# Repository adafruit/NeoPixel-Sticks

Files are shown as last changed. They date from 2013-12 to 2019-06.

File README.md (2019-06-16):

# NeoPixel Stick

__Format is EagleCAD schematic and board layout__

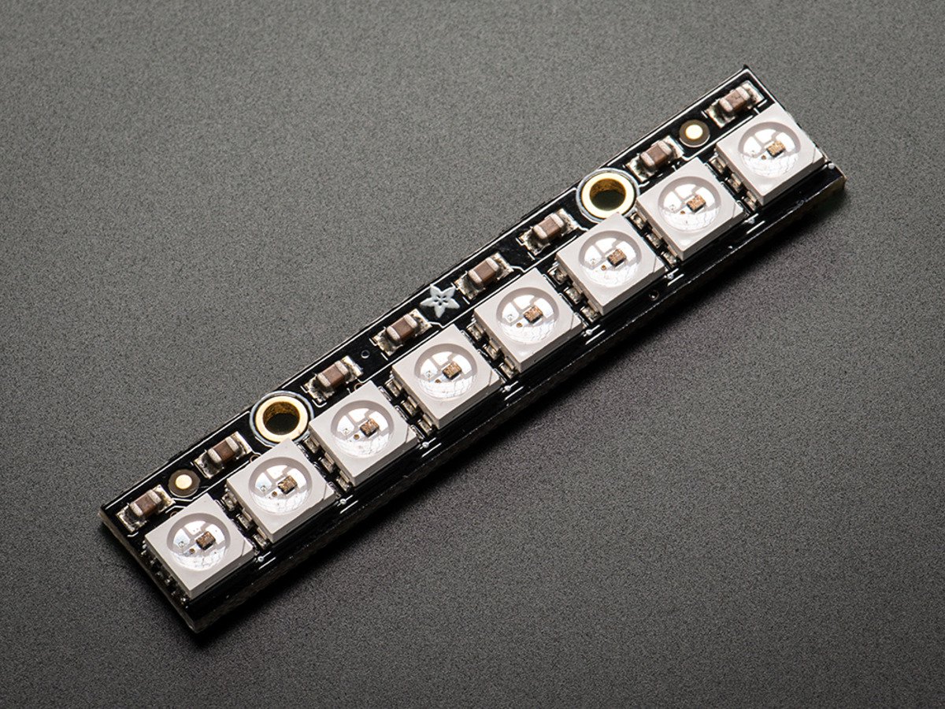
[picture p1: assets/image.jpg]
<a href="http://www.adafruit.com/products/1426"><br/>Click here to purchase one from the Adafruit shop</a>

Make your own little LED strip arrangement with this stick of NeoPixel LEDs. We crammed 8 of the tiny 5050 (5mm x 5mm) smart RGB LEDs onto a PCB with mounting holes and a chainable design. Use only one microcontroller pin to control as many as you can chain together! Each LED is addressable as the driver chip is inside the LED. Each one has ~18mA constant current drive so the color will be very consistent even if the voltage varies, and no external choke resistors are required making the design slim. Power the whole thing with 5VDC (4-7V works) and you're ready to rock.

The LEDs are 'chainable' by connecting the output of one stick into the input of another - see the photo above. There is a single data line with a very timing-specific protocol. Since the protocol is very sensitive to timing, it requires a real-time microconroller such as an AVR, Arduino, PIC, mbed, etc. It cannot be used with a Linux-based microcomputer or interpreted microcontroller such as the netduino or Basic Stamp. Our wonderfully-written [Neopixel library for Arduino supports these pixels!](https://github.com/adafruit/Adafruit_NeoPixel) As it requires hand-tuned assembly it is only for AVR cores but others may have ported this chip driver code so please google around. An 8MHz or faster processor is required.

Comes as a single stick with 8 individually addressable RGB LEDs assembled and tested.

[Our detailed NeoPixel Uberguide has everything you need to use NeoPixels in any shape and size. Including ready-to-go library & example code for the Arduino UNO/Duemilanove/Diecimila, Flora/Micro/Leonardo, Trinket/Gemma, Arduino Due & Arduino Mega/ADK (all versions)](http://learn.adafruit.com/adafruit-neopixel-uberguide)

## License

Adafruit invests time and resources providing this open source design, 
please support Adafruit and open-source hardware by purchasing 
products from Adafruit!

Designed by Adafruit Industries.  
Creative Commons Attribution, Share-Alike license, check license.txt for more information
All text above must be included in any redistribution

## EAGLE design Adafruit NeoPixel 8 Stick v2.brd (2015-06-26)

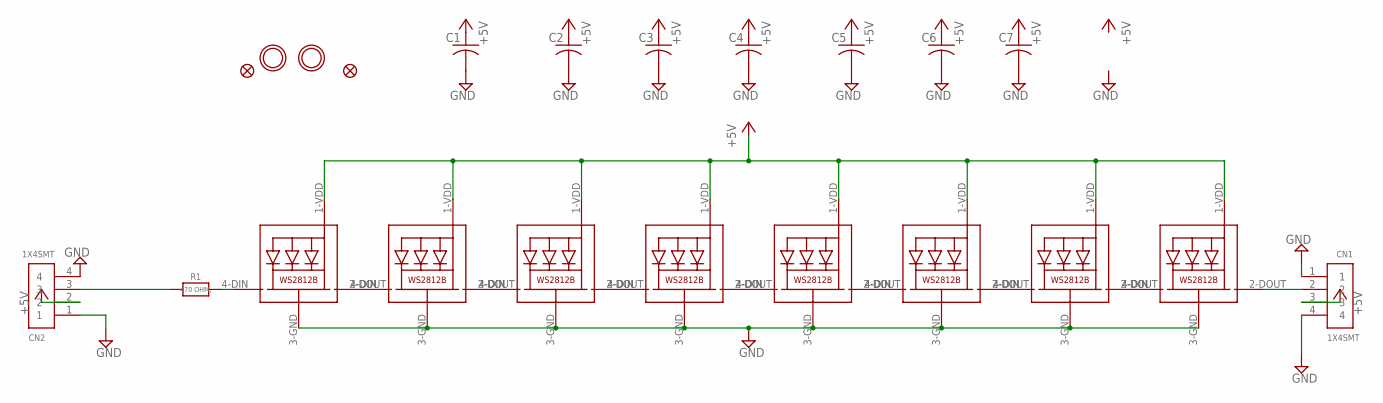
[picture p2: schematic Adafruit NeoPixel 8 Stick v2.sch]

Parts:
C1, C2, C3, C4, C5, C6, C7: C-USC0805K; C0805K
CN1, CN2: 1X4SMT; 1X4-SMT
FID1, FID3: FIDUCIAL""; FIDUCIAL_1MM
LED1, LED2, LED3, LED4, LED5, LED6, LED7, LED8: WS2812B5050; WS2812B
R1: 470 OHM,; _0805MP
U$2, U$3: MOUNTINGHOLE2.0; MOUNTINGHOLE_2.0_PLATED

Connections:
+5V: C1.1, C2.1, C3.1, C4.1, C5.1, C6.1, C7.1, CN1.3, CN2.2, LED1.1-VDD (VDD), LED2.1-VDD (VDD), LED3.1-VDD (VDD), LED4.1-VDD (VDD), LED5.1-VDD (VDD), LED6.1-VDD (VDD), LED7.1-VDD (VDD), LED8.1-VDD (VDD)
GND: C1.2, C2.2, C3.2, C4.2, C5.2, C6.2, C7.2, CN1.1, CN1.4, CN2.1, CN2.4, LED1.3-GND (GND), LED2.3-GND (GND), LED3.3-GND (GND), LED4.3-GND (GND), LED5.3-GND (GND), LED6.3-GND (GND), LED7.3-GND (GND), LED8.3-GND (GND)
unnamed: LED1.2-DOUT (DO), LED2.4-DIN (DI)
unnamed: LED2.2-DOUT (DO), LED3.4-DIN (DI)
unnamed: LED3.2-DOUT (DO), LED4.4-DIN (DI)
unnamed: LED4.2-DOUT (DO), LED5.4-DIN (DI)
unnamed: LED5.2-DOUT (DO), LED6.4-DIN (DI)
unnamed: LED6.2-DOUT (DO), LED7.4-DIN (DI)
unnamed: LED7.2-DOUT (DO), LED8.4-DIN (DI)
unnamed: CN2.3, R1.1
unnamed: CN1.2, LED8.2-DOUT (DO)
unnamed: LED1.4-DIN (DI), R1.2

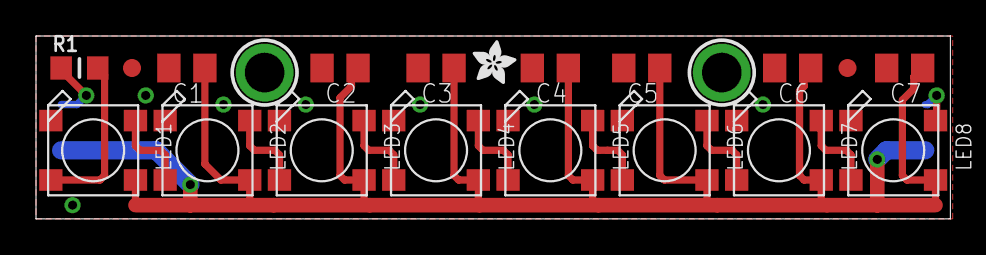
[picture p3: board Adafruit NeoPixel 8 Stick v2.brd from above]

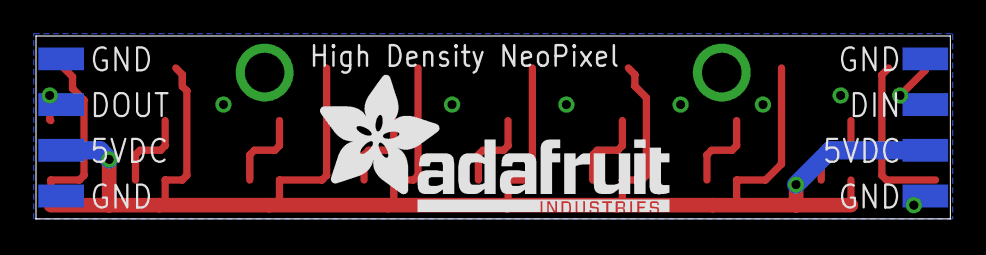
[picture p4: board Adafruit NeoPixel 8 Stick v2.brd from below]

Board: 2 copper layers, 50.8 x 10.2 mm, 24 parts (3 on the bottom side), 12 nets.

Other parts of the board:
U$1: ADAFRUIT_TEXT_20MM
U$4: ADAFRUIT_2.5MM

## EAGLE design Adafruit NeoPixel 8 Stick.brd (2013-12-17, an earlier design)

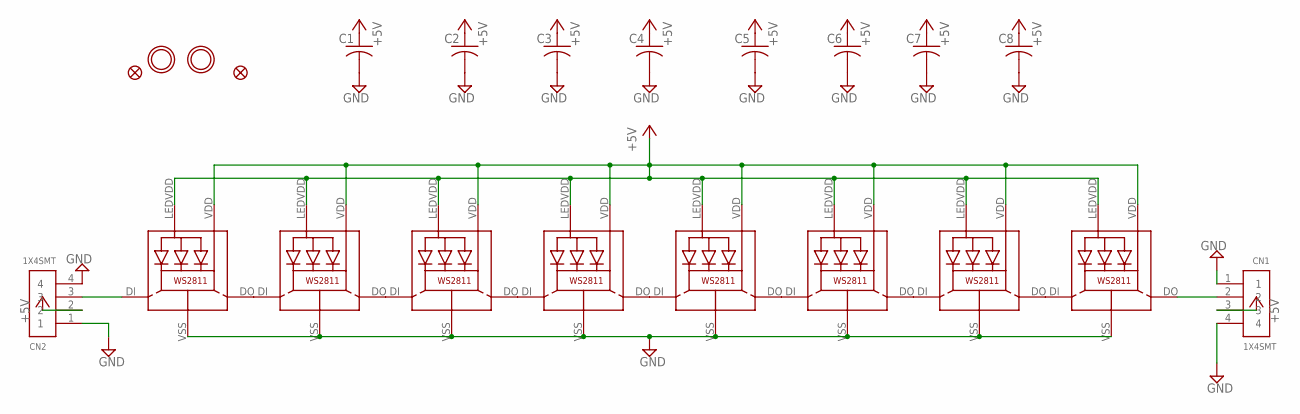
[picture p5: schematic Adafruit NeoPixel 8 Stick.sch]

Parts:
C1, C2, C3, C4, C5, C6, C7, C8: C-USC0805K; C0805K
CN1, CN2: 1X4SMT; 1X4-SMT
FID1, FID3: FIDUCIAL""; FIDUCIAL_1MM
LED1, LED2, LED3, LED4, LED5, LED6, LED7, LED8: WS28115050
U$2, U$3: MOUNTINGHOLE2.0; MOUNTINGHOLE_2.0_PLATED

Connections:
+5V: C1.1, C2.1, C3.1, C4.1, C5.1, C6.1, C7.1, C8.1, CN1.3, CN2.2, LED1.LEDVDD, LED1.VDD, LED2.LEDVDD, LED2.VDD, LED3.LEDVDD, LED3.VDD, LED4.LEDVDD, LED4.VDD, LED5.LEDVDD, LED5.VDD, LED6.LEDVDD, LED6.VDD, LED7.LEDVDD, LED7.VDD, LED8.LEDVDD, LED8.VDD
GND: C1.2, C2.2, C3.2, C4.2, C5.2, C6.2, C7.2, C8.2, CN1.1, CN1.4, CN2.1, CN2.4, LED1.VSS (GND), LED2.VSS (GND), LED3.VSS (GND), LED4.VSS (GND), LED5.VSS (GND), LED6.VSS (GND), LED7.VSS (GND), LED8.VSS (GND)
unnamed: LED1.DO, LED2.DI
unnamed: LED2.DO, LED3.DI
unnamed: LED3.DO, LED4.DI
unnamed: LED4.DO, LED5.DI
unnamed: LED5.DO, LED6.DI
unnamed: LED6.DO, LED7.DI
unnamed: LED7.DO, LED8.DI
unnamed: CN2.3, LED1.DI
unnamed: CN1.2, LED8.DO

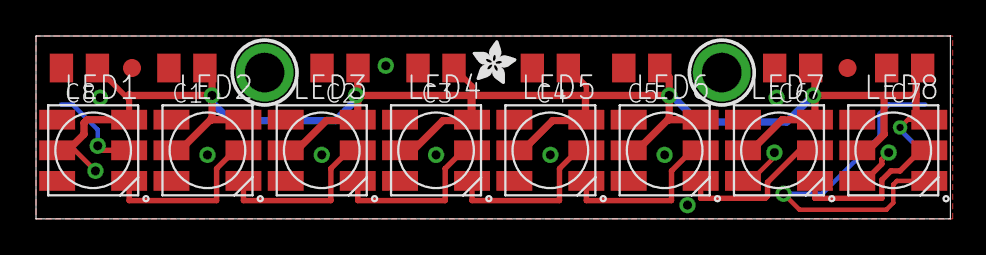
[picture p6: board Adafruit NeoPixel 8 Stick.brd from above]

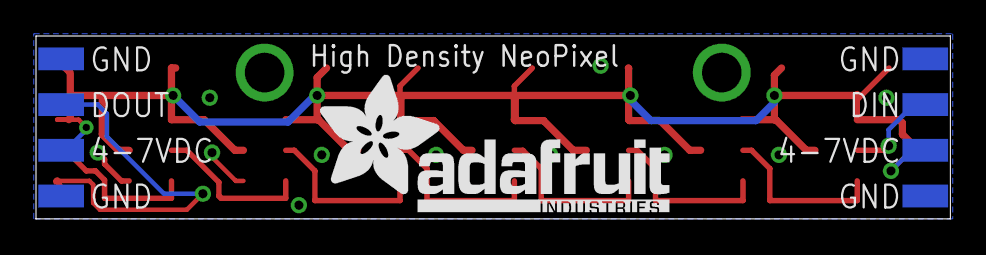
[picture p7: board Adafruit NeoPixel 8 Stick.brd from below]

Board: 2 copper layers, 50.8 x 10.2 mm, 24 parts (3 on the bottom side), 11 nets.

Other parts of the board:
U$1: ADAFRUIT_TEXT_20MM
U$4: ADAFRUIT_2.5MM

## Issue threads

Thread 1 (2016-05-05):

C1..C7 values missing

angel77777, 2016-05-05:
In the Adafruit NeoPixel 8 Stick v2.sch the values of capacitor named C1..C8 are missing

ladyada, 2016-05-06:
there is no strict value, use 1uF+

Closed 2016-05-06.

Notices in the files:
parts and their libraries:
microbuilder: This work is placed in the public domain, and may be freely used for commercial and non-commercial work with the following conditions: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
